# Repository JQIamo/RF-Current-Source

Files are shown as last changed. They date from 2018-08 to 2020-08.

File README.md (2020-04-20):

# RF-Current-Source

A wideband radiofrequency voltage-controlled current source designed by D. Barker and A. Restelli.
Our design is released under the CERN Open Hardware License v1.2 and can be cited using .

The eagle files in this repository will be much easier to use with [eagle-config](https://github.com/JQIamo/eagle-config) installed and configured.

For more detailed documentation, go to the [Wiki](https://github.com/JQIamo/RF-Current-Source/wiki/). A detailed write-up of the RF current source's specifications can be found in our paper.

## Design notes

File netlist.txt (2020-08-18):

# Qucs 0.0.19  /Users/daniel/Documents/GitHub/matched-RF-antenna/RF_VtoI_prj/Converter.sch

.Def:TIamp_sp _netP _netN _netO _netVP _netVN _ref
  Sub:X_1 _ref _netP _netN _netO _netVP _netVN Type="THS3091"
  .Def:SCHEMATIC1_F2 _ref _net1 _net2 _net3 _net4
  CCCS:F_F2 _net1 _net3 _net4 _cnet0 G="1"
  Vdc:VF_F2 _cnet0 _net2 U="0V"
  .Def:End
  .Def:SCHEMATIC1_F1 _ref _net1 _net2 _net3 _net4
  CCCS:F_F1 _net1 _net3 _net4 _cnet1 G="1"
  Vdc:VF_F1 _cnet1 _net2 U="0V"
  .Def:End
  .Def:THS3091 _ref _netINP _netINN _netOUT _netVCC _netVEE
  VCVS:E_E6 _netN33650 _netINPP _netINP _ref G="1"
  R:R_R24 _ref _netN33650 R="700"
  C:C_C6 _ref _netN33650 C="1f"
  Vdc:V_V6 _netIN _netINN U="0.9mV"
  C:C_C3 _ref _netINN C="630f"
  Idc:I_I4 _ref _netINP I="-4.5uA"
  Idc:I_I5 _ref _netINN I="-3uA"
  BJT:Q_Q15 _netINPP _netVCC _netN00923 _ref Type="npn" Area="4" Rc="100" Cje="2e-14" Cjc="2e-14" Kf="1.5e-13" Is="1e-16" Nf="1" Nr="1" Ikf="0" Ikr="0" Vaf="0" Var="0" Ise="0" Ne="1.5" Isc="0" Nc="2" Bf="100" Br="1" Rbm="0" Irb="0" Vje="0.75" Mje="0.33" Vjc="0.75" Mjc="0.33" Xcjc="1" Cjs="0" Vjs="0.75" Mjs="0" Fc="0.5" Vtf="0" Tf="0" Xtf="0" Itf="0" Tr="0"
  BJT:Q_Q16 _netN00889 _netN01029 _netIN _ref Type="npn" Area="4" Rc="100" Cje="2e-14" Cjc="2e-14" Kf="1.5e-13" Is="1e-16" Nf="1" Nr="1" Ikf="0" Ikr="0" Vaf="0" Var="0" Ise="0" Ne="1.5" Isc="0" Nc="2" Bf="100" Br="1" Rbm="0" Irb="0" Vje="0.75" Mje="0.33" Vjc="0.75" Mjc="0.33" Xcjc="1" Cjs="0" Vjs="0.75" Mjs="0" Fc="0.5" Vtf="0" Tf="0" Xtf="0" Itf="0" Tr="0"
  BJT:Q_Q17 _netN01060 _netN01060 _netN013920 _ref Type="npn" Area="12" Rc="100" Cje="2e-14" Cjc="2e-14" Kf="1.5e-13" Is="1e-16" Nf="1" Nr="1" Ikf="0" Ikr="0" Vaf="0" Var="0" Ise="0" Ne="1.5" Isc="0" Nc="2" Bf="100" Br="1" Rbm="0" Irb="0" Vje="0.75" Mje="0.33" Vjc="0.75" Mjc="0.33" Xcjc="1" Cjs="0" Vjs="0.75" Mjs="0" Fc="0.5" Vtf="0" Tf="0" Xtf="0" Itf="0" Tr="0"
  BJT:Q_Q21 _netN00923 _netN01060 _netIN _ref Type="pnp" Area="4" Rc="100" Cje="2e-14" Cjc="2e-14" Kf="1.5e-13" Is="1e-16" Nf="1" Nr="1" Ikf="0" Ikr="0" Vaf="0" Var="0" Ise="0" Ne="1.5" Isc="0" Nc="2" Bf="100" Br="1" Rbm="0" Irb="0" Vje="0.75" Mje="0.33" Vjc="0.75" Mjc="0.33" Xcjc="1" Cjs="0" Vjs="0.75" Mjs="0" Fc="0.5" Vtf="0" Tf="0" Xtf="0" Itf="0" Tr="0"
  BJT:Q_Q22 _netINP _netVEE _netN00889 _ref Type="pnp" Area="4" Rc="100" Cje="2e-14" Cjc="2e-14" Kf="1.5e-13" Is="1e-16" Nf="1" Nr="1" Ikf="0" Ikr="0" Vaf="0" Var="0" Ise="0" Ne="1.5" Isc="0" Nc="2" Bf="100" Br="1" Rbm="0" Irb="0" Vje="0.75" Mje="0.33" Vjc="0.75" Mjc="0.33" Xcjc="1" Cjs="0" Vjs="0.75" Mjs="0" Fc="0.5" Vtf="0" Tf="0" Xtf="0" Itf="0" Tr="0"
  BJT:Q_Q23 _netN01029 _netN01029 _netN01331 _ref Type="pnp" Area="12" Rc="100" Cje="2e-14" Cjc="2e-14" Kf="1.5e-13" Is="1e-16" Nf="1" Nr="1" Ikf="0" Ikr="0" Vaf="0" Var="0" Ise="0" Ne="1.5" Isc="0" Nc="2" Bf="100" Br="1" Rbm="0" Irb="0" Vje="0.75" Mje="0.33" Vjc="0.75" Mjc="0.33" Xcjc="1" Cjs="0" Vjs="0.75" Mjs="0" Fc="0.5" Vtf="0" Tf="0" Xtf="0" Itf="0" Tr="0"
  R:R_R1 _netN01331 _netN01300 R="250"
  R:R_R2 _netN01429 _netN013920 R="250"
  Idc:I_I1 _netN00889 _netVCC I="300uA"
  Idc:I_I2 _netVEE _netN00923 I="300uA"
  Sub:X_F1 _ref _netVCC _netN01300 _netVCC _netLLL Type="SCHEMATIC1_F1"
  Sub:X_F2 _ref _netN01429 _netVEE _netLLL _netVEE Type="SCHEMATIC1_F2"
  Diode:D_D5 _netN29734 _netLLL Area="2" Rs="0.1" Cj0="1e-13" Is="1e-13" N="1" M="0.5" Vj="0.7"
  Diode:D_D6 _netLLL _netN29798 Area="2" Rs="0.1" Cj0="1e-13" Is="1e-13" N="1" M="0.5" Vj="0.7"
  Vdc:V_V7 _netN29734 _netVCC U="-2.3V"
  Vdc:V_V8 _netN29798 _netVEE U="2.3V"
  C:C_C1 _netEREF _netLLL C="0.66p"
  R:R_R3 _netEREF _netLLL R="900k"
  R:R_R11 _netEREF _netINT R="1000"
  C:C_C5 _netEREF _netINT C="400f"
  VCCS:G_G1 _netLLL _netINT _netEREF _netEREF G="-1m"
  VCVS:E_E1 _netN02361 _netVCC _netN02648 _netEREF G="-1"
  VCVS:E_E2 _netN02418 _netN02628 _netVEE _netEREF G="1"
  Diode:D_D3 _netN02743 _netN02648 Area="8" Rs="0.1" Cj0="1e-13" Is="1e-13" N="1" M="0.5" Vj="0.7"
  Diode:D_D4 _netN02628 _netN028591 Area="8" Rs="0.1" Cj0="1e-13" Is="1e-13" N="1" M="0.5" Vj="0.7"
  R:R_R5 _netN02855 _netN02743 R="5"
  R:R_R7 _netN028591 _netN02855 R="5"
  VCVS:E_E101 _netVCC _netAVG _netVEE _netVEE G="0.5"
  VCVS:E_E102 _netAVG _netEREF _ref _ref G="1"
  VCVS:E_E103 _netVCC _netDIFF _ref _netVEE G="0.5"
  VCVS:E_E104 _netDIFF _netLSHIFT _ref _netDDROP G="1"
  VCVS:E_E105 _netLSHIFT _netINT _netN02361 _ref G="1"
  VCVS:E_E106 _netLSHIFT _netINT _netN02418 _ref G="-1"
  C:C_C2 _ref _netOUT C="0.7p"
  L:L_L1 _netN02855 _netOUT L="1n"
  Idc:I_I3 _netVEE _netVCC I="4.85mA"
  Vdc:V_V102 _netDDROP _ref U="0.65"
  .Def:End
.Def:End

.Def:TI_THS3091 _net0 _net2 _net4 _net3 _net1
Sub:X1 _net0 _net1 _net2 _net3 _net4 gnd Type="TIamp_sp"
.Def:End

R:R1 gnd Vin R="50 Ohm" Temp="26.85" Tc1="0.0" Tc2="0.0" Tnom="26.85"
C:C1 _net0 Vin C="220 nF" V=""
Vdc:V2 _net1 gnd U="15 V"
Sub:SUB1 Vin _net2 _net3 _net1 _net4 Type="TI_THS3091"
.DC:DC1 Temp="26.85" reltol="0.001" abstol="1 pA" vntol="1 uV" saveOPs="no" MaxIter="150" saveAll="no" convHelper="none" Solver="CroutLU"
Eqn:Eqn2 Rf="215" Export="yes"
Eqn:Eqn3 Rg="23.7" Export="yes"
Eqn:Eqn5 Lg="220*10^-9" Export="yes"
L:L2 _net5 _net2 L="Lc" I=""
L:L1 gnd _net6 L="Lg" I=""
R:R2 _net6 _net4 R="Rg" Temp="26.85" Tc1="0.0" Tc2="0.0" Tnom="26.85"
IProbe:Pr1 _net7 _net4
R:R3 _net8 _net7 R="Rf" Temp="26.85" Tc1="0.0" Tc2="0.0" Tnom="26.85"
VProbe:Pr2 _net2 gnd
IProbe:Pr4 _net5 _net9
Vdc:V3 gnd _net3 U="15 V"
Eqn:Eqn7 Cp="1/(Lc*(2*pi*10^8)^2)" Export="yes"
VProbe:Pr3 _net10 gnd
R:R6 gnd _net10 R="50 Ohm" Temp="26.85" Tc1="0.0" Tc2="0.0" Tnom="26.85"
R:R4 gnd _net8 R="10 Ohm" Temp="26.85" Tc1="0.0" Tc2="0.0" Tnom="26.85"
C:C3 _net8 _net10 C="2 nF" V=""
Vac:V1 _net0 gnd U="0.028 V" f="ft" Phase="0" Theta="0"
R:R5 _net8 _net9 R="0.1 Ohm" Temp="26.85" Tc1="0.0" Tc2="0.0" Tnom="26.85"
.SW:SW2 Sim="SW1" Type="lin" Param="ft" Start="1 MHz" Stop="100 MHz" Points="100"
.SW:SW1 Sim="TR1" Type="lin" Param="Lc" Start="250 nH" Stop="270 nH" Points="2"
C:C2 _net8 _net2 C="Cp" V=""
.TR:TR1 Type="lin" Start="1.5 us" Stop="2.6 us" Points="1101" IntegrationMethod="Trapezoidal" Order="2" InitialStep="1 ns" MinStep="1e-16" MaxIter="150" reltol="0.001" abstol="1 pA" vntol="1 uV" Temp="26.85" LTEreltol="1e-3" LTEabstol="1e-6" LTEfactor="1" Solver="CroutLU" relaxTSR="no" initialDC="yes" MaxStep="0"

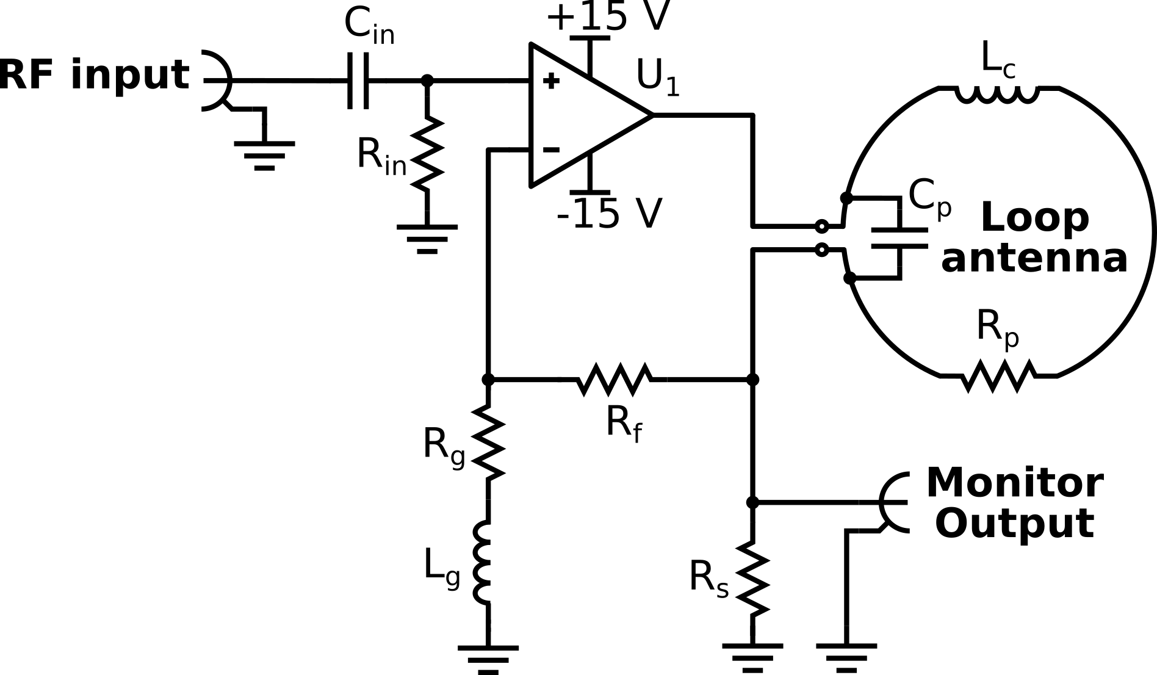
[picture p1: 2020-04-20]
Documentation/schematic.png

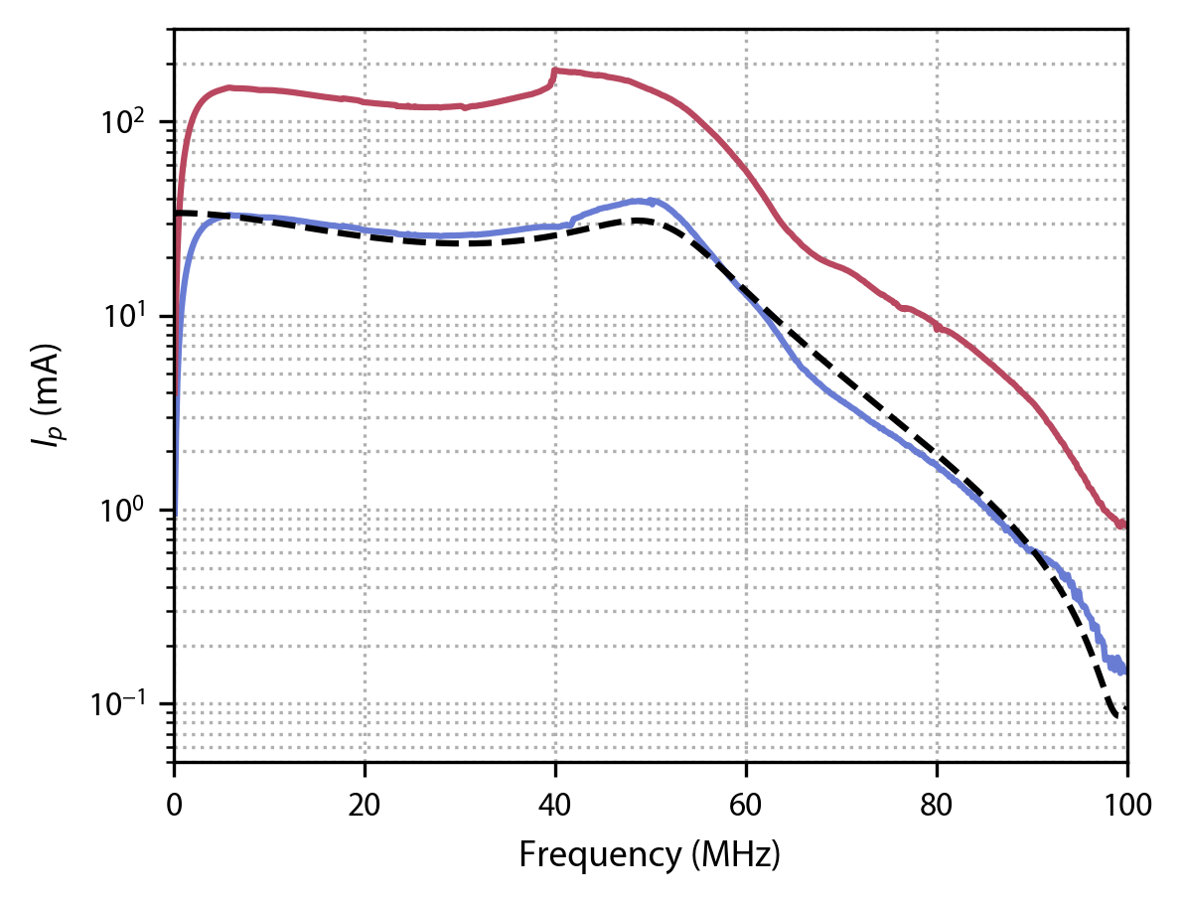
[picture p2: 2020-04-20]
Documentation/Loop_antenna_data.png

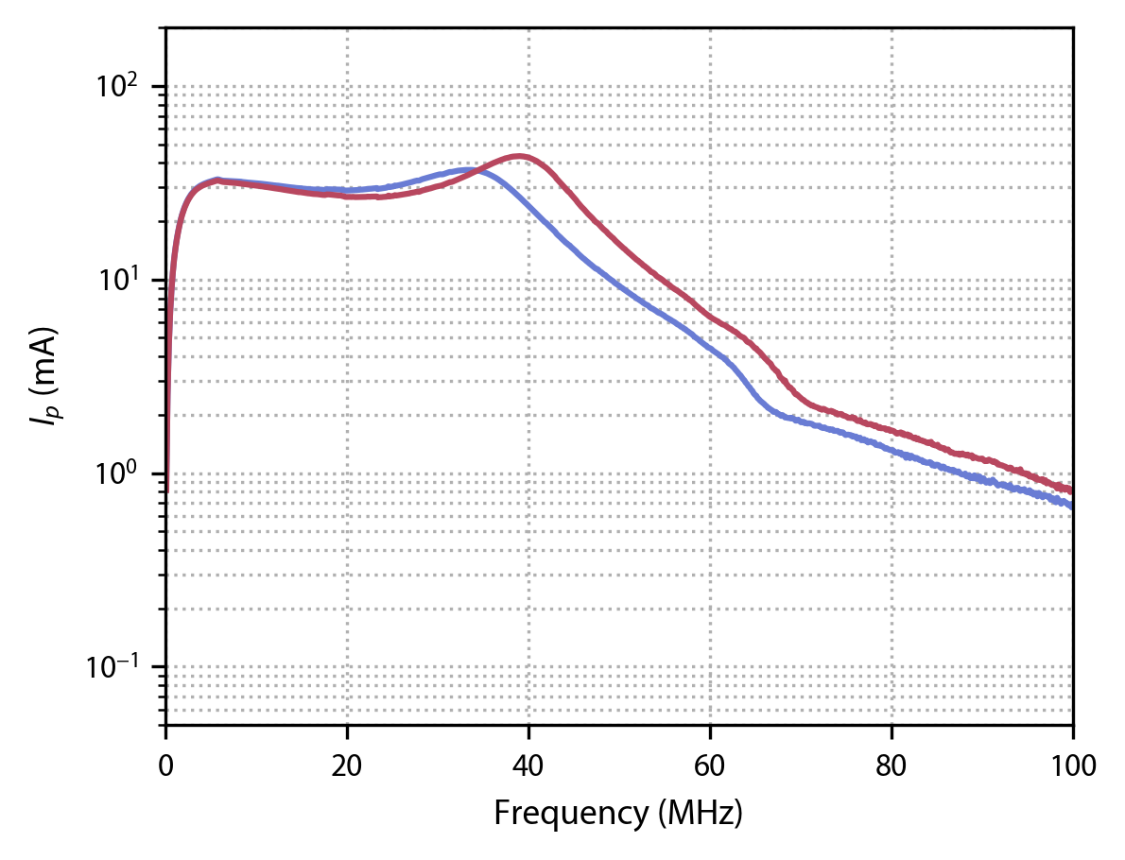
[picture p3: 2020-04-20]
Documentation/D_antenna_data.png

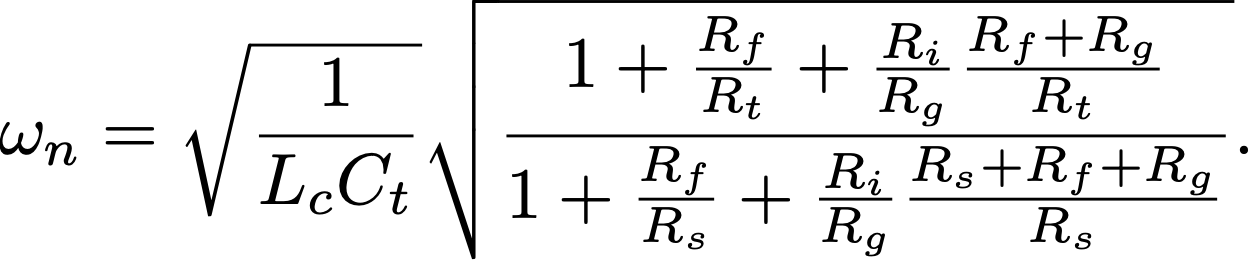
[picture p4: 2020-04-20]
Documentation/omega_n.png

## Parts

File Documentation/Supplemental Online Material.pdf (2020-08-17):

Supplemental Material for: A radiofrequency voltage-controlled current source for

quantum spin manipulation

D.S. Barker,¹ A. Restelli,¹

J.A. Fedchak,²

J. Scherschligt,² and S. Eckel²

1)Joint Quantum Institute, University of Maryland and National Institute of Standards and

Technology

College Park, MD 20742, USA

2)Sensor Science Division, National Institute of Standards and Technology

Gaithersburg, MD 20899, USA

(Dated: 12 August 2020)

Closed-loop transfer function: Applying Kirchoff’s rules to the RF VCCS circuit (see Fig. 1

in the main text) and modelling the current-feedback amplifier (CFA) as suggested in KarkiS1

yields:

Vout − Vs = IcLc s,

Vout − Vs =

Ip
Cp s

,

Vs = IsRs

,
Vs − Vi = IfRf

,
Vi = Ig(Rg + Lg s),

Vin − Vi = RiVout

1 + RtCts
Rt

,

Ic + Ip = If + Is

,

Ig = Vout

1 + RtCts
Rt

+ If

(S1)

Here, s is the complex frequency; Vout is the output voltage of the CFA; Vs

is the voltage across

Rs

; Vi

is the voltage at the inverting input of the CFA; Vin is the voltage at the noninverting input of

the CFA; Ic

is the current passing through the antenna coil Lc

; Ip is the current passing through Cp;

Is

is the current passing through Rs ; If

is the current passing through Rf

; Ig is the current passing

through Rg; and the other symbols are defined in the main text. We have also assumed that the

antenna’s parasitic resistance Rp is negligible. Eliminating Vout, Vi
, Ic

, Ip, Is

, If

, and Ig in Eqs. S1

leads to the closed-loop transfer function

H(s) =

Vs

Vin

=

Rs
Rf
Rt + RtCpLc s

2
+
Rg + Lg s

Rt + Lc s + Rt(Cp + Ct)Lc s

2

,
Rf
Rg + Ri + Lg s

1 + RtCts

Rs + Lc s + RsCpLc s
2

+ s

RsLcLg s
1 + Rt(Cp + Ct)s
+ RsLg
Ri + Rt + RtRiCts

+ LcRi

1 + RtCts

Rs + Lg s + RsCpLg s

2

+ Rg

Ri
1 + RtCts

Rs + Lc s + RsCpLc s

2
+ Rs
Rt + Lc s + Rt(Cp + Ct)Lc s

2

(S2)

The transadmittance of the RF VCCS is then

Y(ω) =

H(s → jω)

Rs
. | (S3)

The linear response of the RF VCCS is given by Y(ω)Vp, where Vp is the RF input voltage ampli-

tude. We have found that the full transfer function of Eq. S2 does not usefully guide selection of

Rf

, Rg, and Lg. Rather, we select Rf so that Rf + Rp + jωLc approaches the recommended value

of the feedback impedance as ω approaches the operating bandwidth of the CFA and choose Rg to

achieve the desired DC gain G.

S2 We then take Cp = 0 and Lg = 0 to reduce the number of poles

in H(s), allowing us to find that the natural frequency ωn and damping factor ζ are

ωn =

r
1
LcCt

vuut 1 +
Rf
Rt

+

Ri
Rg

Rf +Rg
Rt
1 +

Rf
Rs

+

Ri
Rg

Rs+Rf +Rg
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
Rt(Rf + Rs)
Rs(Rf + Rt)

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
RtRs
(Rf + Rt)(Rf + Rs)

(S4)

Antennas with negligible Rp and Lc & 10 nH will exhibit underdamped poles (ζ < 1). To flatten

the response of the RF VCCS, we add a real pole to the transfer function using Lg. When Ri Rg,

the pole introduced by Lg occurs at s = Rg/Lg, so Lg must be larger than Rg/ωn to flatten Y(ω).

Open-loop transfer function: To find the open-loop transfer function, we ground the nonin-

verting input of the CFA and break the feedback loop at the CFA’s output. The input voltage Vin is

now applied directly to the antenna. Applying Kirchoff’s rules to the open-loop circuit leads to

Vin − Vs = IcLc s,

Vin − Vs =

Ip
Cp s

,

Vs = IsRs

,
Vs − Vi = IfRf

,
Vi = Ig(Rg + Lg s),

Vi = −IeRi

,

Vout =

IeRt
1 + RtCts

,

Ic + Ip = If + Is

,
Ig = Ie + If

,

(S5)

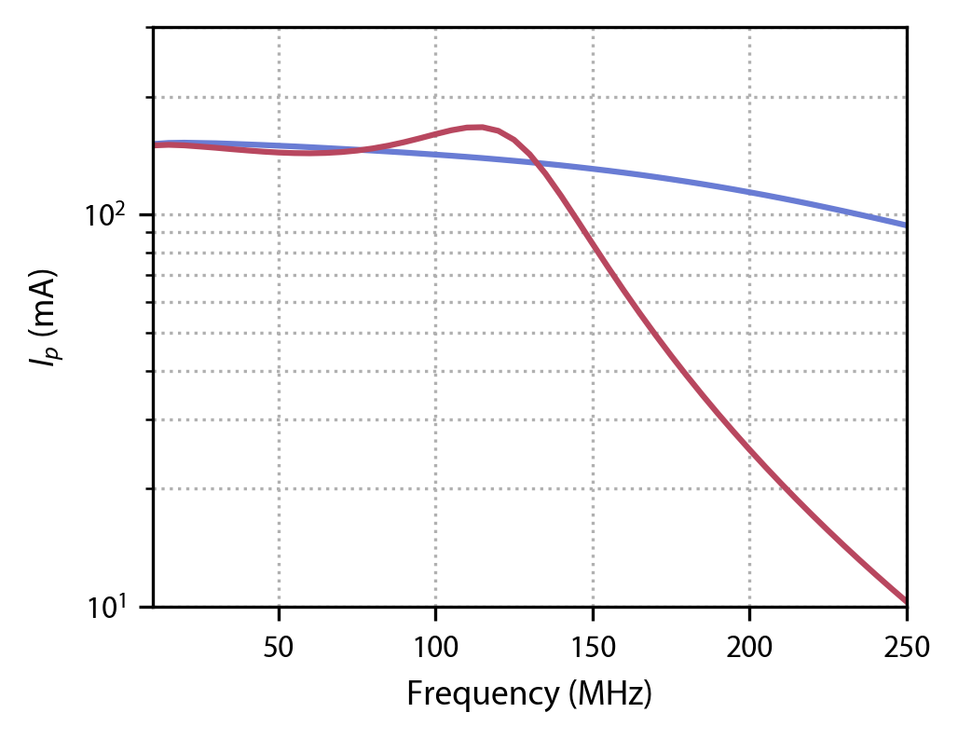
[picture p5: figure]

FIG. S1. Simulations of a 25 nH antenna (red) and the design from the supplemental material of Fratila et

al.S3 (blue). The RF input voltage for both curves is Vp = 127 mV.

where Ie

is the error current.S1 We eliminate Vs , Vi

, Ic

, Ip, Is

, If

, Ig, and Ie

in Eqs. S5 to find the

open-loop transfer function

G(s) =

Vout

Vin

= −

RsRt
Rg + Lg s

1 + CpLc s

2
,
1 + CtRts

Rg
RiRs + Lc(Ri + Rs)s + CpLcRiRss

2

+ Rf

Rg + Ri + Lg s

Rs + Lc s + CpLcRss

2

+ s

(Lc + Lg)RiRs + LcLg(Ri + Rs)s + CpLcLgRiRss

2

(S6)

Once we select component values using H(s) (see above), we can compute G(s) to estimate the

gain margin and phase margin of the RF VCCS.

Low-inductance antennas: We have simulated the performance of two low-inductance anten-

nas. The first is an Lc = 25 nH loop antenna with Rp = 100 mΩ and Cp = 1 pF. The second is the

broadband coil design described in the supplemental material of Fratila et al.S3 with Lc = 0.4 nH,

Rp = 5 Ω, and Cp = 0 pF. The results of transient simulations of the two antennas are shown in

Fig. S1. For the 25 nH antenna simulation, Rf = 561 Ω, Rg = 62 Ω, Rs = 8.33 Ω (after accounting

for the parallel impedance of a hypothetical spectrum analyzer), Lg = 130 nH ≈ 1.3Rg/ωn. For

the broadband coil simulation, Rf = 866 Ω, Rg = 95.3 Ω, Rs = 8.33 Ω, Lg = 0 nH. The simulated

bandwidth of the RF VCCS is approximately 140 MHz for the 25 nH antenna and approximately

210 MHz for the broadband coil. We note that the THS3091 SPICE model underestimates the

device bandwidth for G = 10,

S4 so wider operating bandwidths may be achievable in practice.

REFERENCES

S1
J. Karki, Voltage Feedback Vs Current Feedback Op Amps, Texas Instruments (1998), SLVA051.

S2THS309x High-voltage, Low-distortion, Current-feedback Operational Amplifiers, Texas Instru-

ments (2015), SLOS423H.

S3R. M. Fratila, M. V. Gomez, S. Sykora, and A. H. Velders, ´ | Nature Communications 5, 3025

(2014). (http://dx.doi.org/10.1038/ncomms4025)

S4THS3091 PSpice Model, Texas Instruments (2016), Rev. A.

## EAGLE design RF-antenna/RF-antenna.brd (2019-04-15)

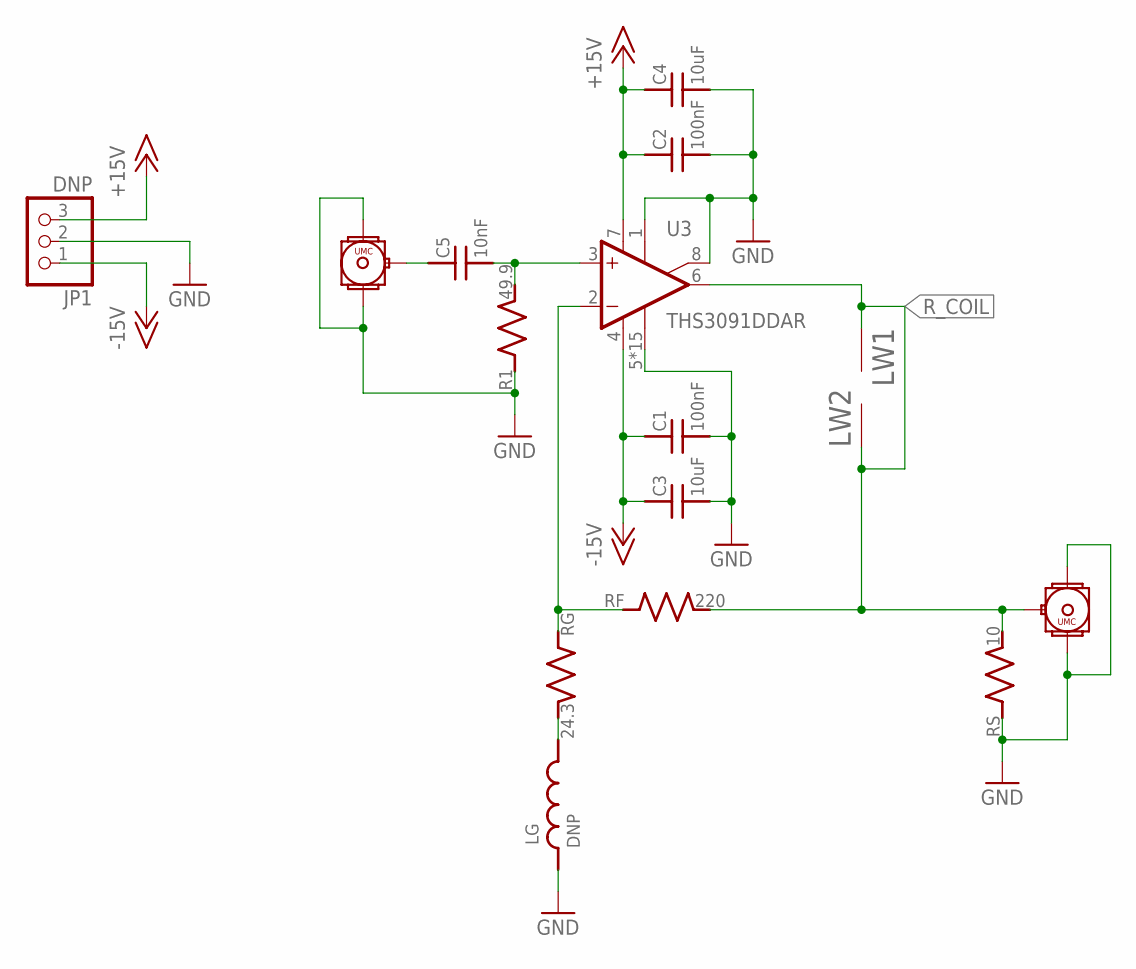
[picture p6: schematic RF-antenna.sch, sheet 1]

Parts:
C1, C2: 100nF; C_MLCC_0603; PARTNO 06035C104K4Z2A
C3, C4: 10uF; C_MLCC_1206; PARTNO CL31A106MBHNNNE
C5: 10nF; C_MLCC_0402; PARTNO CL05B103KB5NNNC
CON1, CON2: UMC_CONNECTORREGULAR; UMC_CONNECTOR; PARTNO 1909763-1
JP1: DNP; 1X03; PARTNO 640456-3
LG: DNP; 1008
LW1, LW2: LITZ_TERM; LITZ_100MHZ
R1: 49.9; R_0402; PARTNO ERA-2AEB49R9X
RF: 220; R_0603; PARTNO TNPW0603220RBEEA
RG: 24.3; R_0402; PARTNO RP73PF1E24R3BTD
RS: 10; R_1206; PARTNO PHP01206E10R0BST5
U3: THS3091DDAR; DDA8_2P28X2P28; PARTNO THS3091DDAR

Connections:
+15V: C2.P$1 (1), C4.P$1 (1), JP1.3, U3.7 (V+); also elsewhere on the board
-15V: C1.P$1 (1), C3.P$1 (1), JP1.1, U3.4 (V-); also elsewhere on the board
GND: C1.P$2 (2), C2.P$2 (2), C3.P$2 (2), C4.P$2 (2), CON1.P$2, CON1.P$3, CON2.P$2, CON2.P$3, JP1.2, LG.P$1 (1), R1.P$1 (1), RS.P$1 (1), U3.1 (ON1), U3.5 (OPT), U3.8 (ON2), U3.EPAD (OPT), U3.P$1 (OPT), U3.P$2 (OPT), U3.P$3 (OPT), U3.P$4 (OPT), U3.P$5 (OPT), U3.P$6 (OPT), U3.P$7 (OPT), U3.P$8 (OPT), U3.P$9 (OPT), U3.P$10 (OPT), U3.P$11 (OPT), U3.P$12 (OPT), U3.P$13 (OPT); also elsewhere on the board
unnamed: RF.P$1 (1), RG.P$1 (1), U3.2 (-IN)
unnamed: C5.P$2 (2), R1.P$2 (2), U3.3 (+IN)
unnamed: C5.P$1 (1), CON2.P$1
unnamed: LG.P$2 (2), RG.P$2 (2)
R_COIL: CON1.P$1, LW1.T1, LW2.T1, RF.P$2 (2), RS.P$2 (2), U3.6 (OUT)

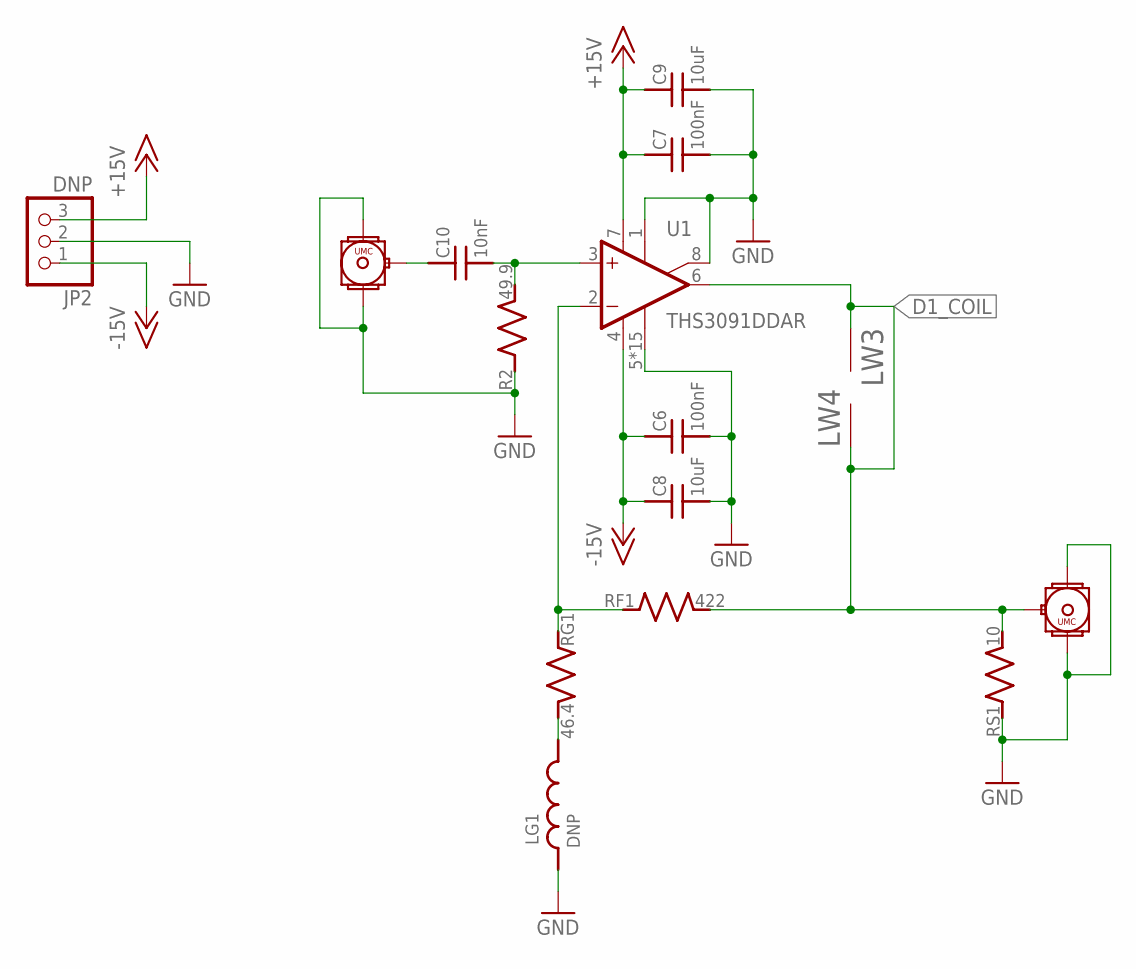
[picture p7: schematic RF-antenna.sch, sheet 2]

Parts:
C6, C7: 100nF; C_MLCC_0603; PARTNO 06035C104K4Z2A
C8, C9: 10uF; C_MLCC_1206; PARTNO CL31A106MBHNNNE
C10: 10nF; C_MLCC_0402; PARTNO CL05B103KB5NNNC
CON3, CON4: UMC_CONNECTORREGULAR; UMC_CONNECTOR; PARTNO 1909763-1
JP2: DNP; 1X03; PARTNO 640456-3
LG1: DNP; 1008
LW3, LW4: LITZ_TERM; LITZ_100MHZ
R2: 49.9; R_0402; PARTNO ERA-2AEB49R9X
RF1: 422; R_0603; PARTNO TNPW0603422RBEEA
RG1: 46.4; R_0402; PARTNO RP73PF1E46R4BTD
RS1: 10; R_1206; PARTNO PHP01206E10R0BST5
U1: THS3091DDAR; DDA8_2P28X2P28; PARTNO THS3091DDAR

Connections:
+15V: C7.P$1 (1), C9.P$1 (1), JP2.3, U1.7 (V+); also elsewhere on the board
-15V: C6.P$1 (1), C8.P$1 (1), JP2.1, U1.4 (V-); also elsewhere on the board
D1_COIL: CON4.P$1, LW3.T1, LW4.T1, RF1.P$2 (2), RS1.P$2 (2), U1.6 (OUT)
GND: C6.P$2 (2), C7.P$2 (2), C8.P$2 (2), C9.P$2 (2), CON3.P$2, CON3.P$3, CON4.P$2, CON4.P$3, JP2.2, LG1.P$1 (1), R2.P$1 (1), RS1.P$1 (1), U1.1 (ON1), U1.5 (OPT), U1.8 (ON2), U1.EPAD (OPT), U1.P$1 (OPT), U1.P$2 (OPT), U1.P$3 (OPT), U1.P$4 (OPT), U1.P$5 (OPT), U1.P$6 (OPT), U1.P$7 (OPT), U1.P$8 (OPT), U1.P$9 (OPT), U1.P$10 (OPT), U1.P$11 (OPT), U1.P$12 (OPT), U1.P$13 (OPT); also elsewhere on the board
unnamed: RF1.P$1 (1), RG1.P$1 (1), U1.2 (-IN)
unnamed: C10.P$2 (2), R2.P$2 (2), U1.3 (+IN)
unnamed: C10.P$1 (1), CON3.P$1
unnamed: LG1.P$2 (2), RG1.P$2 (2)

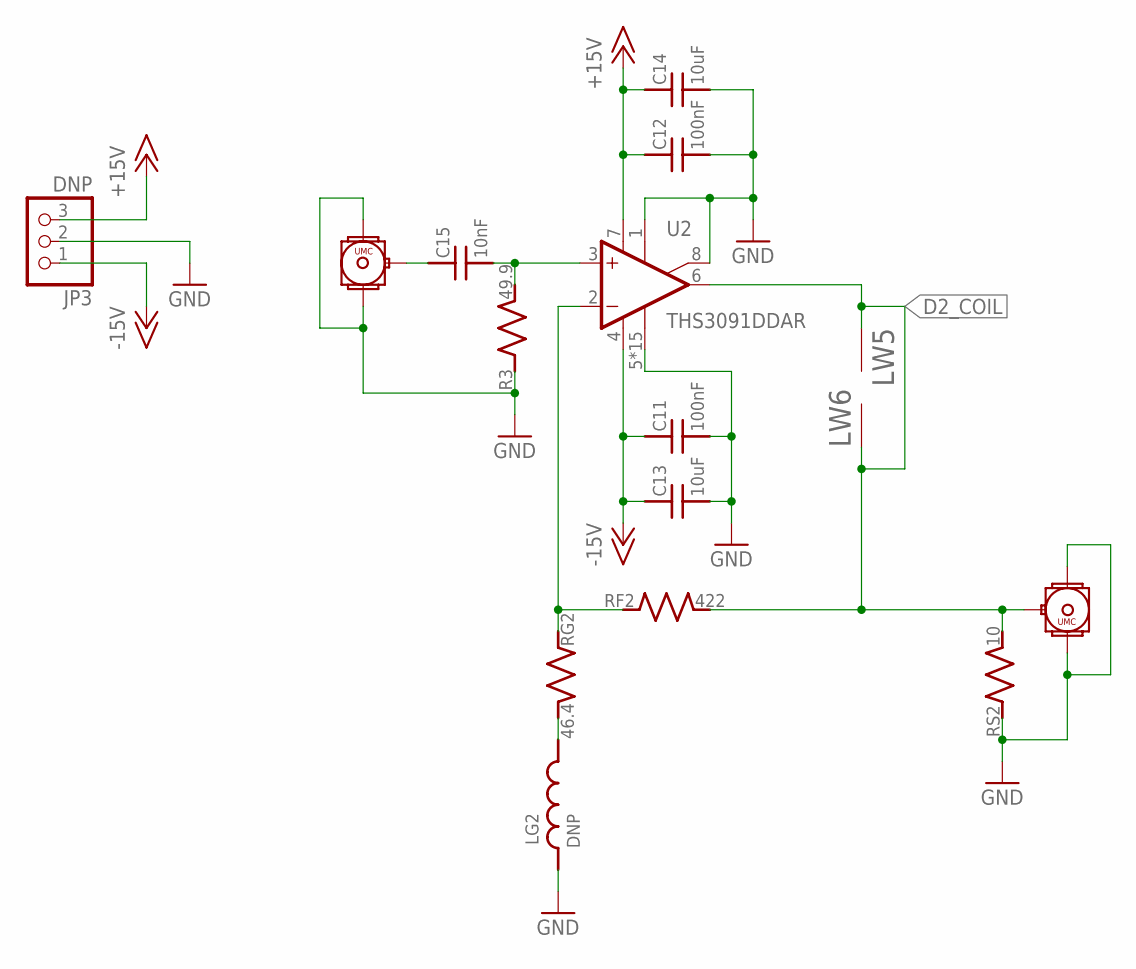
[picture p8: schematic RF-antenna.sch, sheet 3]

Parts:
C11, C12: 100nF; C_MLCC_0603; PARTNO 06035C104K4Z2A
C13, C14: 10uF; C_MLCC_1206; PARTNO CL31A106MBHNNNE
C15: 10nF; C_MLCC_0402; PARTNO CL05B103KB5NNNC
CON5, CON6: UMC_CONNECTORREGULAR; UMC_CONNECTOR; PARTNO 1909763-1
JP3: DNP; 1X03; PARTNO 640456-3
LG2: DNP; 1008
LW5, LW6: LITZ_TERM; LITZ_100MHZ
R3: 49.9; R_0402; PARTNO ERA-2AEB49R9X
RF2: 422; R_0603; PARTNO TNPW0603422RBEEA
RG2: 46.4; R_0402; PARTNO RP73PF1E46R4BTD
RS2: 10; R_1206; PARTNO PHP01206E10R0BST5
U2: THS3091DDAR; DDA8_2P28X2P28; PARTNO THS3091DDAR

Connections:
+15V: C12.P$1 (1), C14.P$1 (1), JP3.3, U2.7 (V+); also elsewhere on the board
-15V: C11.P$1 (1), C13.P$1 (1), JP3.1, U2.4 (V-); also elsewhere on the board
D2_COIL: CON6.P$1, LW5.T1, LW6.T1, RF2.P$2 (2), RS2.P$2 (2), U2.6 (OUT)
GND: C11.P$2 (2), C12.P$2 (2), C13.P$2 (2), C14.P$2 (2), CON5.P$2, CON5.P$3, CON6.P$2, CON6.P$3, JP3.2, LG2.P$1 (1), R3.P$1 (1), RS2.P$1 (1), U2.1 (ON1), U2.5 (OPT), U2.8 (ON2), U2.EPAD (OPT), U2.P$1 (OPT), U2.P$2 (OPT), U2.P$3 (OPT), U2.P$4 (OPT), U2.P$5 (OPT), U2.P$6 (OPT), U2.P$7 (OPT), U2.P$8 (OPT), U2.P$9 (OPT), U2.P$10 (OPT), U2.P$11 (OPT), U2.P$12 (OPT), U2.P$13 (OPT); also elsewhere on the board
unnamed: RF2.P$1 (1), RG2.P$1 (1), U2.2 (-IN)
unnamed: C15.P$2 (2), R3.P$2 (2), U2.3 (+IN)
unnamed: C15.P$1 (1), CON5.P$1
unnamed: LG2.P$2 (2), RG2.P$2 (2)

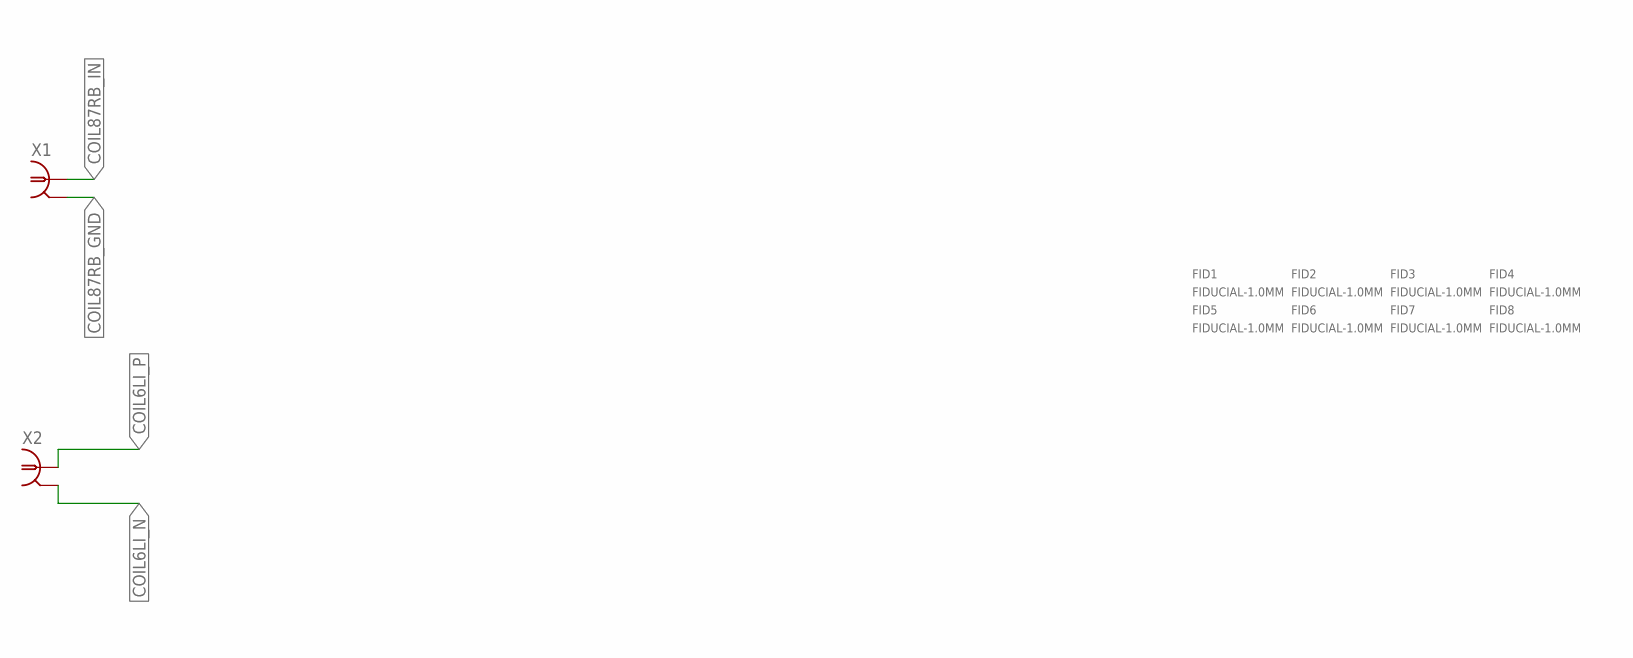
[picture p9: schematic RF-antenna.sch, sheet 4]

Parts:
FID1, FID2, FID3, FID4, FID5, FID6, FID7, FID8: FIDUCIAL-1.0MM; FID_1.0MM
X1, X2: SMA-V; PARTNO 5-1814832-1

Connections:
COIL6LI_N: X2.GND1 (2), X2.GND2 (2), X2.GND3 (2), X2.GND4 (2)
COIL6LI_P: X2.RF (1)
COIL87RB_GND: X1.GND1 (2), X1.GND2 (2), X1.GND3 (2), X1.GND4 (2)
COIL87RB_IN: X1.RF (1)

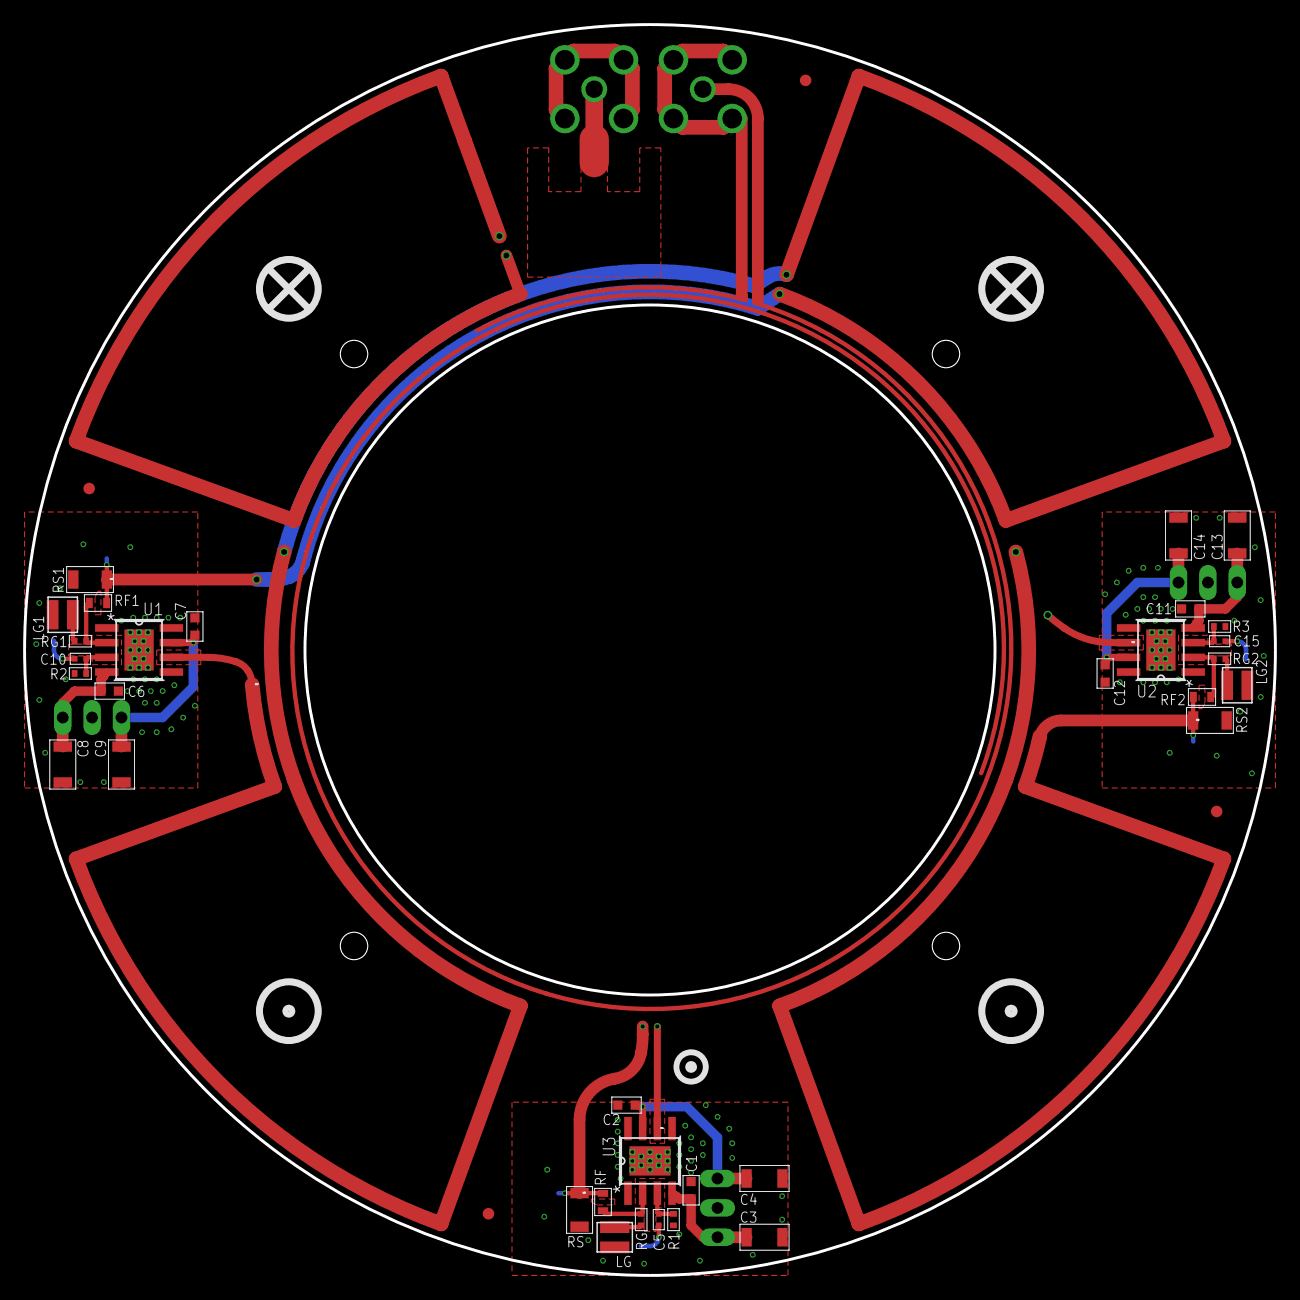
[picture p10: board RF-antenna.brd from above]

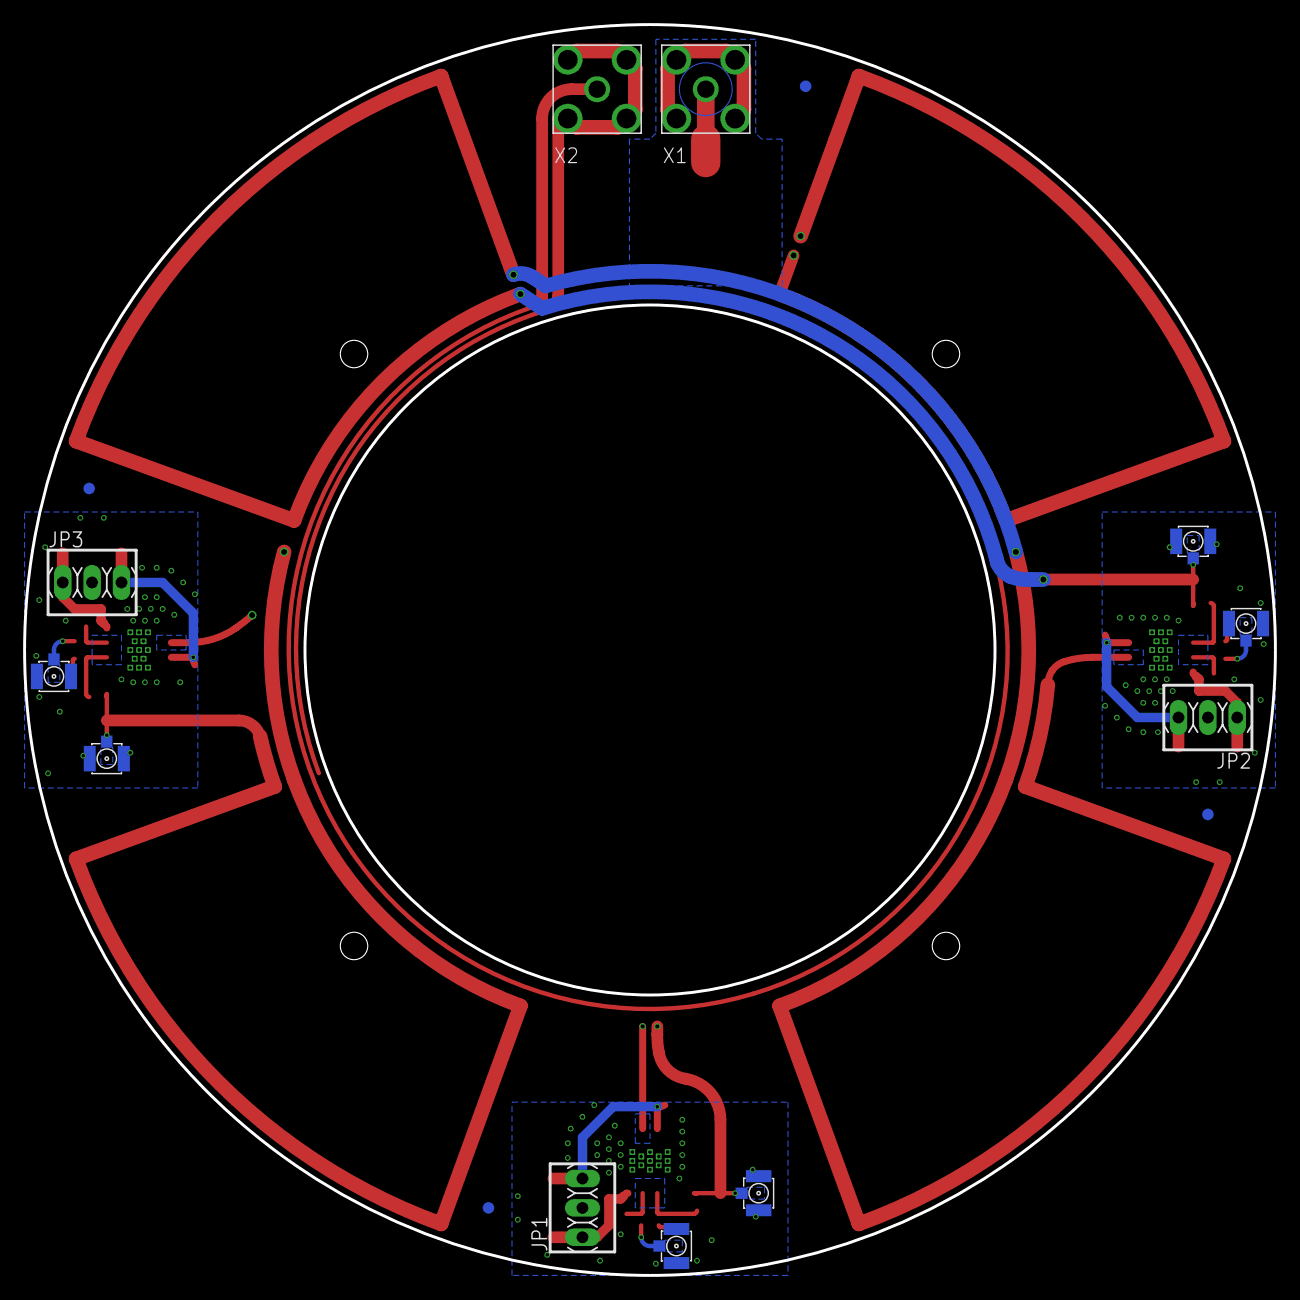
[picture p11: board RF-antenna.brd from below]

Board: 4 copper layers, 108.2 x 108.2 mm, 58 parts (15 on the bottom side), 20 nets.

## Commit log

2018-03-02 Initial Commit
    Pushing antenna files to git.
    DSB
    [RF-antenna.brd, RF-antenna.sch]
2018-03-20 Adding parts for footprinting
    Added a bunch of test components to get an idea of how tight the design
    will be. Also corrected the keepout areas.
    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
    [RF-antenna.brd, RF-antenna.sch]
2018-03-21 More footprints
    Added a few more component footprints to see what is up and test layout.
    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
    [RF-antenna.brd, RF-antenna.sch]
2018-05-25 add library
    Adding a library for design of Litz wire.
    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
2018-06-04 Quick Push
    Added buffers and minimal schematic.
    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
    [RF-antenna.brd, RF-antenna.sch]
2018-06-07 Zeroth order design
    Quick layout for testing with Alessandro.
    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
    [RF-antenna.brd, RF-antenna.sch]
2018-08-24 Starting full board layout
    Got the VtoI converter designed and have started laying out the RF antennas.
    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
    [RF-VtoI.brd, RF-VtoI.sch, RF-antenna.brd]
2018-08-27 Finished 1st order prototype
    Ready to discuss with Alessandro and Steve. Rough estimate that one board will generate 20 kHz Rabi frequencies with the circular coil.
    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
    [RF-antenna.brd]
2018-08-29 Qucs simulation
    Pushing the qucs simulation of the RF V to I converter.
    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
    [Converter.sch, TI_THS3091.sch]
2018-08-30 Fix antenna polarity
    The polarity of half of each of the D-shaped antennas was incorrect. I've adjusted so that the D antennas produce B fields pointing along the diagonal as desired.
    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
    [RF-antenna.brd]
2018-10-18 Test board ready
    Pushing the prepared test board complete with 230 MHz and 6.8 GHz antennas for hyperfine control.
    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
    [RF-antenna.brd, RF-antenna.sch]
2018-10-18 Success
    Got COMSOL to push, now updating with additional COMSOL and files for Macrofab.
    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
    [RF-antenna.brd, RF-antenna.sch]
2018-10-19 85Rb antenna
    Adding the patch antenna design for 85Rb.
    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
2018-12-21 Antenna B
    Added 7Li and 85Rb HF antennas. Also switched polarity of loop antenna.
    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
    [RF-antenna_B.brd, RF-antenna_B.sch]
2018-12-21 MacroFab files
    Uploading Macrofab files for antenna B.
    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
2019-01-31 Initial loop data
    I placed 560 nH for Lg, 422 Ohm for Rf, 47 Ohm for Rg. The loop antenna has a flat response out to about 40 MHz and the parasitic capacitor resonance is out at about 100 MHz. I should be able to do m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
2019-02-12 More Data
    More data on the RF antennas. Need to move out to NIST to check thermal instability issues on the Bitter coil.
    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
2019-02-13 Data on the Bitter coil
    Adding data taken at NIST with the antenna attached to the Bitter coil.
    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
    [D1_422Ohm_50mv_Bitter.CSV, D2_422Ohm_50mv_Bitter.CSV, Loop_215Ohm_90mv_Bitter.CSV]
2019-02-22 Updating microwave antenna sims
    Updating the microwave antenna simulations to reflect the actual high frequency performance of MacroFab's FR4.
    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
2019-03-06 Finished Er fitting
    Fit the data for Er of MacroFab FR4. The Debye model isn't a great fit, but it's kind of close. Need to simulate antennas to cross-check.
    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
2019-04-08 Push updated antennas
    Pushing the adjusted antenna designs to model on a faster computer.
    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
2019-04-09 New Rb87 Antenna
    Pushing the redesigned Rb87 antenna.
    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
2019-04-11 New 6Li antenna
    Finished a spiral dipole design for the 6Li antenna. Testing indicates that it should be okay for Er > 3.8 (the low end of the FR4 spec). Note that the bitter coils presence changes the resonance and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
2019-04-15 New 87Rb and 6Li antennas
    I updated the eagle files with the new 87Rb and 6Li antenna designs from COMSOL.
    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
    [RF-antenna.brd, RF-antenna.sch]
2019-04-15 New BOM
    Pushing a new BOM for the RF-antenna PCB.
    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
2019-04-15 Updated values
    Changed values in BOM to reflect results from prototype antennas.
    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
    [RF-antenna.brd, RF-antenna.sch]
2019-05-10 Remove microwave antennas
    Removing microwave antennas due to Git LFS limits.
    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
2020-02-25 Power amp comparison
    Adding simulation of the RF antenna with a power amplifier.
    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
    [Antenna.sch, Converter.sch]
2020-02-25 Figs for wiki
    Pushing a couple figures for the wiki.
    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
2020-03-13 More simulations
    Pushing new simulations for phase margin and gain margin.
    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
    [Converter.sch, Converter_Stability.sch]
2020-04-08 Updated simulations
    Added parameter sweeps to better fit the loop inductance and corrected the circuit for the prescence of the spectrum analyzer.
    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
    [Converter.sch]
2020-04-08 Transimpedance Simulation
    Adding simulation to estimate the transimpedance of the CFA.
    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
    [Converter.sch, Converter_Stability.sch, Transimpedance.sch]
2020-04-11 add Ri
    Adding effect of Ri to the transfer function.
    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
    [Converter.sch]
2020-07-17 Updated simulations
    Pushing the most recent transient simulation code. New data is not included (file too large), so simulations will have to be rerun.
    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
    [Converter.sch]
2020-08-17 Update Docs
    Adding new simulation results and transfer function derivation.
    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
    [25nH_Transient_127mV_Sweep_561Ohm_130nH.csv, Fratila_Transient_127mV_Sweep.csv, Fratila_Transient_200mV_Sweep.csv]
2020-08-18 Update simulations
    Pushing most recent transient simulation versions of qucs files.
    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
    [Antenna.sch, Converter.sch]
2021-11-04 Push new notebooks
    Pushing the new mathematica simulations of the RF antennas.
    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
2021-11-24 Push new antenna calculations
    Pushing design for transverse RF antennas.
    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

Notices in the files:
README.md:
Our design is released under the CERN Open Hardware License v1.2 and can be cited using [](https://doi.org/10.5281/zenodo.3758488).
